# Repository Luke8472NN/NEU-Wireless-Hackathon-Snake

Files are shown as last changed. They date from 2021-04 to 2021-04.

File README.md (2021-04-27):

# NEU-Wireless-Hackathon-Snake
Northeastern University Wireless Club 11/11/16 Hackathon Snake Game.

Copied from my old profile, https://github.com/Luke8472

Eternally grateful for https://github.com/devendrashivraj for the board design!

## Description
A Snake Game coded in Arduino and uploaded to an Arduino Uno. A PCB was designed as a shield for the Arduino Uno, and to house all electronic components.

 

## How it Works
1) Turn the game on, using the power switch located in the upper left corner of the PCB.
2) Press the joystick once, to start playing the game.
3) The direction of the snake can be controlled using the joystick.
4) The speed of the snake can be controlled using the potentiometer located to the left of the joystick.
5) The option for walls on or off can be controlled by the switch below the potentiometer. </br>
   a) If the walls are on, the user loses if the snake hits the edge of the display. </br>
   b) If the walls are off, the snake can go out one edge, and come in through the other (world wraps around).
6) The score is displayed above the joystick, and represents the number of candies eaten by the snake.
7) If the game is left idle for more than 15 seconds, a Snake AI will begin playing the game.

## Goal of the Game
Eat all of the candy without having the snake cross over itself. Once the snake grows to the size of the display (score = 128), the user wins.

## Prerequisites
LedControl library: https://github.com/wayoda/LedControl

## Board Design


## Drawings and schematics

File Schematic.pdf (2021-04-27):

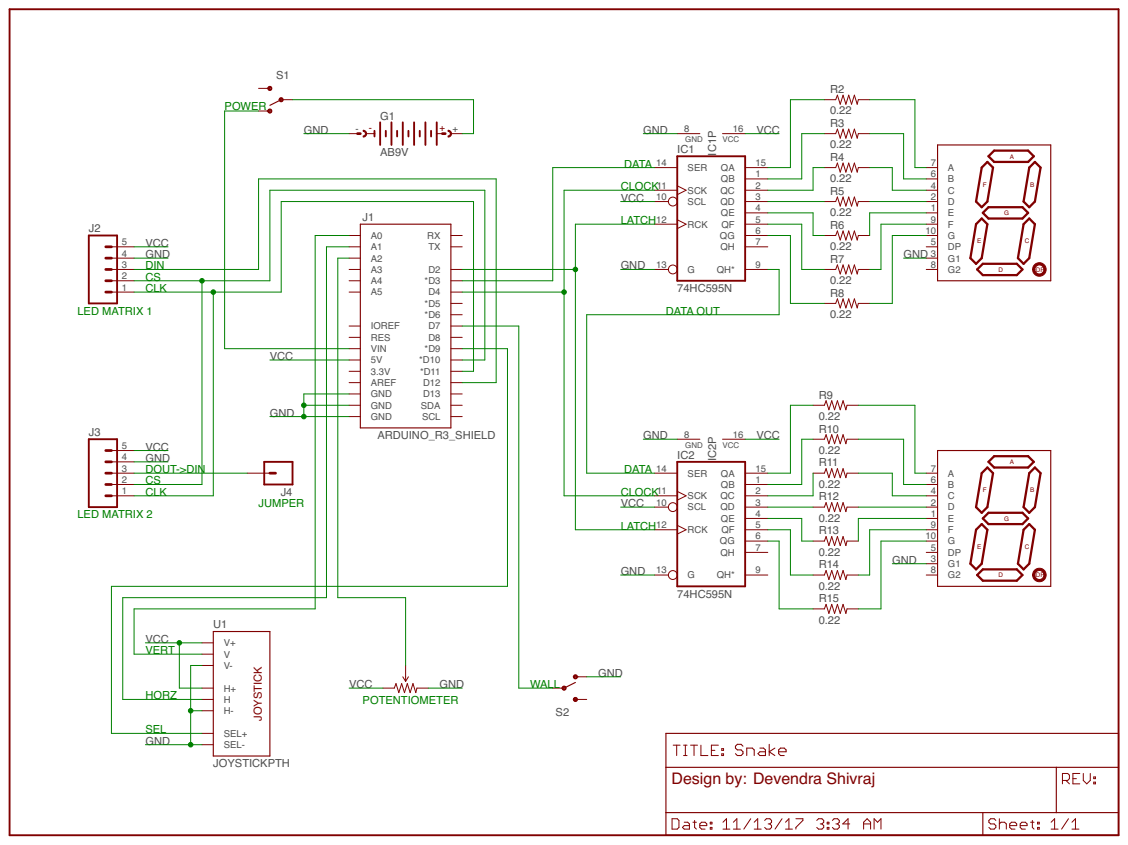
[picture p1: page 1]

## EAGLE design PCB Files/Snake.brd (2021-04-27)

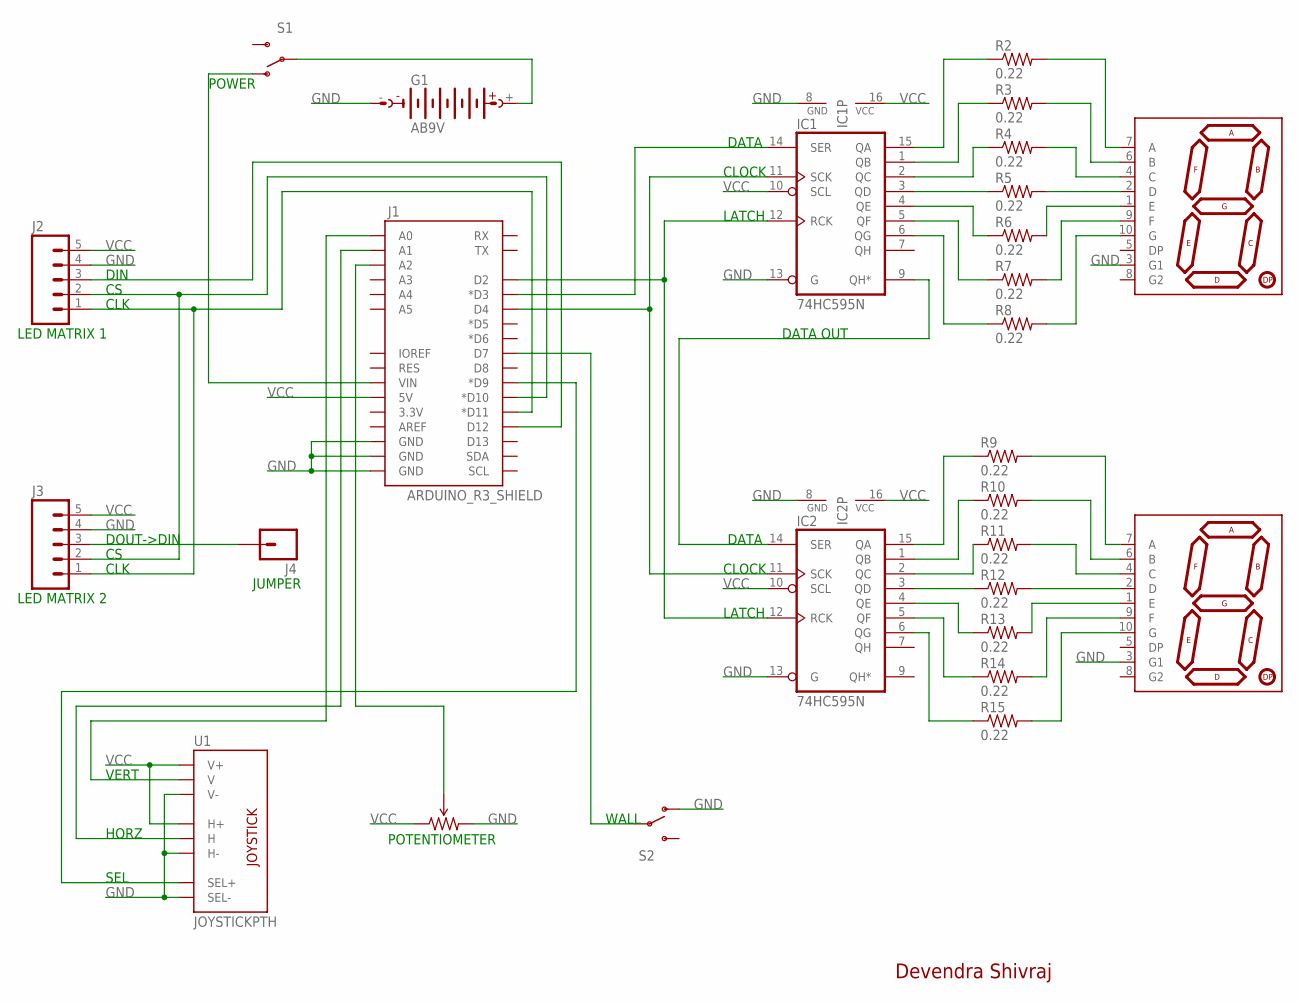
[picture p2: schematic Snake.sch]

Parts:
G1: AB9V
IC1, IC2: 74HC595N; DIL16
J1: ARDUINO_R3_SHIELD; UNO_R3_SHIELD
J2, J3: M05PTH; 1X05
J4: M01PTH; 1X01
R1: TSR-3386; 3386U
R2, R3, R4, R5, R6, R7, R8, R9, R10, R11, R12, R13, R14, R15: 0.22; 0805
S1, S2: SWITCH-SPDTPTH; SWITCH-SPDT
U1: JOYSTICKPTH; JOYSTICK
U$1, U$2: 7-SEGMENT-DISPLAYPTH; 7-SEGMENT-DISPLAY

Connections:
+: G1.+, S1.2
A2: J1.A2, R1.2 (WIPER)
CLK: J1.D11 (*D11), J2.1, J3.1
CLOCK: IC1.11 (SCK), IC2.11 (SCK), J1.D4
CS: J1.D10 (*D10), J2.2, J3.2
DATA: IC1.14 (SER), J1.D3 (*D3)
DATA_SHIFT: IC1.9 (QH*), IC2.14 (SER)
DIN: J1.D12, J2.3
GND: G1.-, IC1.8 (GND), IC1.13 (G), IC2.8 (GND), IC2.13 (G), J1.GND@0 (GND), J1.GND@1 (GND), J1.GND@2 (GND), J2.4, J3.4, R1.3 (CW), S2.1 (O), U1.B2A (SEL-), U1.H3 (H-), U1.V3 (V-), U$1.3 (G1), U$2.3 (G1)
HORZ: J1.A1, U1.H2 (H)
LATCH: IC1.12 (RCK), IC2.12 (RCK), J1.D2
unnamed: J3.3, J4.1
unnamed: J1.VIN, S1.1 (O)
unnamed: IC1.15 (QA), R2.1
unnamed: IC1.1 (QB), R3.1
unnamed: IC1.2 (QC), R4.1
unnamed: IC1.3 (QD), R5.1
unnamed: IC1.4 (QE), R6.1
unnamed: IC1.5 (QF), R7.1
unnamed: IC1.6 (QG), R8.1
unnamed: R2.2, U$1.7 (A)
unnamed: R3.2, U$1.6 (B)
unnamed: R4.2, U$1.4 (C)
unnamed: R5.2, U$1.2 (D)
unnamed: R6.2, U$1.1 (E)
unnamed: R7.2, U$1.9 (F)
unnamed: R8.2, U$1.10 (G)
unnamed: IC2.15 (QA), R9.1
unnamed: J1.D7, S2.2
unnamed: IC2.1 (QB), R10.1
unnamed: IC2.2 (QC), R11.1
unnamed: IC2.3 (QD), R12.1
unnamed: IC2.4 (QE), R13.1
unnamed: IC2.5 (QF), R14.1
unnamed: IC2.6 (QG), R15.1
unnamed: R9.2, U$2.7 (A)
unnamed: R10.2, U$2.6 (B)
unnamed: R11.2, U$2.4 (C)
unnamed: R12.2, U$2.2 (D)
unnamed: R13.2, U$2.1 (E)
unnamed: R14.2, U$2.9 (F)
unnamed: R15.2, U$2.10 (G)
SEL: J1.D9 (*D9), U1.B1A (SEL+)
VCC: IC1.10 (SCL), IC1.16 (VCC), IC2.10 (SCL), IC2.16 (VCC), J1.5V, J2.5, J3.5, R1.1 (CCW), U1.H1 (H+), U1.V1 (V+)
VERT: J1.A0, U1.V2 (V)

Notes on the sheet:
DATA
CLOCK
LATCH
DATA OUT
VERT
HORZ
SEL
WALL
DIN
CLK
POWER
LED MATRIX 1
LED MATRIX 2
POTENTIOMETER
JUMPER
DOUT->DIN
Devendra Shivraj

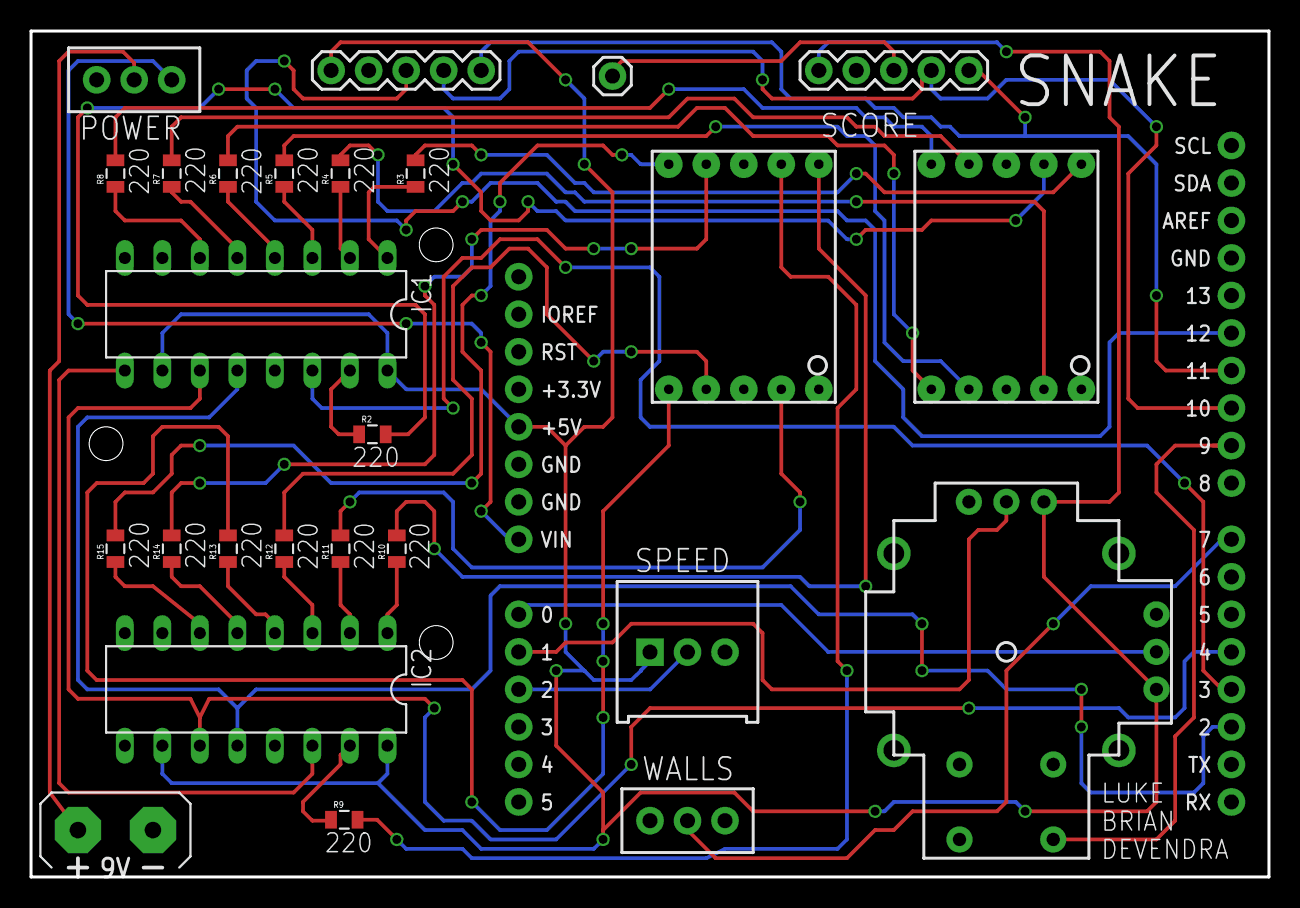
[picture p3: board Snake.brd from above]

Board: 2 copper layers, 83.8 x 57.3 mm, 27 parts (0 on the bottom side), 45 nets.

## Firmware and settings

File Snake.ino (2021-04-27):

#include "LedControl.h"
#include <avr/pgmspace.h>
const byte SPACE[5] PROGMEM = {B00000000, B00000000, B00000000, B00000000, B00000000}; // SPACE
const byte A[5] PROGMEM = {B01111110, B00010001, B00010001, B01111110, B00000000}; // A
const byte B[5] PROGMEM = {B01111111, B01001001, B01001001, B00110110, B00000000}; // B
const byte C[5] PROGMEM = {B00111110, B01000001, B01000001, B00100010, B00000000}; // C
const byte D[5] PROGMEM = {B01111111, B01000001, B01000001, B00111110, B00000000}; // D
const byte E[5] PROGMEM = {B01111111, B01001001, B01001001, B01000001, B00000000}; // E
const byte F[5] PROGMEM = {B01111111, B00001001, B00001001, B00000001, B00000000}; // F
const byte G[5] PROGMEM = {B00111110, B01000001, B01001001, B01111010, B00000000}; // G
const byte H[5] PROGMEM = {B01111111, B00001000, B00001000, B01111111, B00000000}; // H
const byte I[5] PROGMEM = {B01000001, B01111111, B01000001, B00000000, B00000000}; // I
const byte J[5] PROGMEM = {B00110000, B01000000, B01000001, B00111111, B00000000}; // J
const byte K[5] PROGMEM = {B01111111, B00001000, B00010100, B01100011, B00000000}; // K
const byte L[5] PROGMEM = {B01111111, B01000000, B01000000, B01000000, B00000000}; // L
const byte M[5] PROGMEM = {B01111111, B00000010, B00001100, B00000010, B01111111}; // M
const byte N[5] PROGMEM = {B01111111, B00000100, B00001000, B00010000, B01111111}; // N
const byte O[5] PROGMEM = {B00111110, B01000001, B01000001, B00111110, B00000000}; // O
const byte P[5] PROGMEM = {B01111111, B00001001, B00001001, B00000110, B00000000}; // P
const byte Q[5] PROGMEM = {B00111110, B01000001, B01000001, B10111110, B00000000}; // Q
const byte R[5] PROGMEM = {B01111111, B00001001, B00001001, B01110110, B00000000}; // R
const byte S[5] PROGMEM = {B01000110, B01001001, B01001001, B00110010, B00000000}; // S
const byte T[5] PROGMEM = {B00000001, B00000001, B01111111, B00000001, B00000001}; // T
const byte U[5] PROGMEM = {B00111111, B01000000, B01000000, B00111111, B00000000}; // U
const byte V[5] PROGMEM = {B00001111, B00110000, B01000000, B00110000, B00001111}; // V
const byte W[5] PROGMEM = {B00111111, B01000000, B00111000, B01000000, B00111111}; // W
const byte X[5] PROGMEM = {B01100011, B00010100, B00001000, B00010100, B01100011}; // X
const byte Y[5] PROGMEM = {B00000111, B00001000, B01110000, B00001000, B00000111}; // Y
const byte Z[5] PROGMEM = {B01100001, B01010001, B01001001, B01000111, B00000000}; // Z
const int SEGMENT[10] PROGMEM = {63, 6, 91, 79, 102, 109, 125, 7, 127, 103}; // 7 segment display

/*
 pin D12 is connected to the DataIn
 pin D11 is connected to the CLK
 pin D10 is connected to CS
 
 pin A0 is connected to Vertical
 pin A1 is connected to Horizontal
 pin D9 is connected to the button
 */
LedControl lc = LedControl(12,11,10,2);

int latchPin = 2;
int dataPin = 3;
int clockPin = 4;

int toggle, dir;
int array[16][8]; //column, row
int len = 1;
bool isCandy = true, hasLost = true;
int headX = 0, headY = 4;
int del = 50;
//bool isOpenWall = true; // now digitalRead(7) is used
bool isAI = false;
int candyX, candyY;
int brightness = 1;

void setup() {
  /*
   The MAX72XX is in power-saving mode on startup,
   we have to do a wakeup call
   */
  lc.shutdown(0,false);
  lc.shutdown(1,false);
  
  /* Set the brightness to a medium values */
  lc.setIntensity(0,brightness);
  lc.setIntensity(1,brightness);
  
  /* and clear the display */
  lc.clearDisplay(0);
  lc.clearDisplay(1);

  pinMode(9, INPUT);
  digitalWrite(9, HIGH); // to toggle button
  pinMode(7, INPUT);
  digitalWrite(7, HIGH); // to isOpenWall switch

  Serial.begin(9600);

  pinMode(latchPin, OUTPUT);
  pinMode(dataPin, OUTPUT);
  pinMode(clockPin, OUTPUT);
}

void displayBoard() {
  for(int i=0; i<16; i++) {
    for(int j=0; j<8; j++) {
      if(i<8) {
        lc.setLed(0,i,j,array[i][j]!=0);
      }
      else {
        lc.setLed(1,i-8,j,array[i][j]!=0);
      }
    }
  }
}
void negDisplayBoard() {
  for(int i=0; i<16; i++) {
    for(int j=0; j<8; j++) {
      if(i<8) {
        lc.setLed(0,i,j,array[i][j]==0);
      }
      else {
        lc.setLed(1,i-8,j,array[i][j]==0);
      }
    }
  }
}

void increment() {
  if(digitalRead(7) == LOW) { // swich is closed so walls are open //!isOpenWall) {
    if((dir==0 && headY==7) || (dir==1 && headX==15) || (dir==2 && headY==0) || (dir==3 && headX==0)) {
      hasLost = true;
    }
  }
  
  if(!hasLost) {
    for(int i=0; i<16; i++) {
      for(int j=0; j<8; j++) {
        if(array[i][j] > 0) {
          array[i][j]++;
        }
      }
    }
    
    if(dir==0) {
      headY = (headY+1)%8;
      isCandy = (array[headX][headY]==-1);
      hasLost = (array[headX][headY]>1);
      array[headX][headY] = 1;
    }
    else if(dir==1) {
      headX = (headX+1)%16;
      isCandy = (array[headX][headY]==-1);
      hasLost = (array[headX][headY]>1);
      array[headX][headY] = 1;
    }
    else if(dir==2) {
      headY = (headY+7)%8;
      isCandy = (array[headX][headY]==-1);
      hasLost = (array[headX][headY]>1);
      array[headX][headY] = 1;
    }
    else {
      headX = (headX+15)%16;
      isCandy = (array[headX][headY]==-1);
      hasLost = (array[headX][headY]>1);
      array[headX][headY] = 1;
    }
    
    if(isCandy) {
      len++;
    }
    else {
      for(int i=0; i<16; i++) {
        for(int j=0; j<8; j++) {
          if(array[i][j] == len+1) {
            array[i][j] = 0;
          }
        }
      }
    }
  }
}

void scrollText(String s, int wait) {
  //int i=-17; // -17 to make text scroll from right with 17 col offset
  //while(true) {
  for(int i=-17; i<wait/50 - 17; i++) { // wait i time scrolling before going to animation
    for(int j=0; j<8; j++) {
      if(j+i >= 0) {
        byte testByte = getTextByte(s,(j+i)%(6*s.length()));
        lc.setRow(0,j,testByte);
      }
    }
    for(int j=0; j<8; j++) { // for some reason it didn't do j=0 to 15 & board j/8
      if(j+i+8 >= 0) {
        byte testByte = getTextByte(s,(j+i+8)%(6*s.length()));
        lc.setRow(1,j,testByte);
      }
    }
    delay(50);
    //i++;
    
    if(digitalRead(9) == LOW) {hasLost = false; isAI = false; return;}
  }
  hasLost = false; // new since method's outer for loop
  isAI = true;
}

byte getTextByte(String s, int byteNum) {
  byte z = B00000000;
  if(s[byteNum/6] == ' ') {if(byteNum%6 == 5) {return z;} else {return pgm_read_byte_near(SPACE + byteNum%6);} }
  else if(s[byteNum/6] == 'A') {if(byteNum%6 == 5) {return z;} else {return pgm_read_byte_near(A + byteNum%6);} }
  else if(s[byteNum/6] == 'B') {if(byteNum%6 == 5) {return z;} else {return pgm_read_byte_near(B + byteNum%6);} }
  else if(s[byteNum/6] == 'C') {if(byteNum%6 == 5) {return z;} else {return pgm_read_byte_near(C + byteNum%6);} }
  else if(s[byteNum/6] == 'D') {if(byteNum%6 == 5) {return z;} else {return pgm_read_byte_near(D + byteNum%6);} }
  else if(s[byteNum/6] == 'E') {if(byteNum%6 == 5) {return z;} else {return pgm_read_byte_near(E + byteNum%6);} }
  else if(s[byteNum/6] == 'F') {if(byteNum%6 == 5) {return z;} else {return pgm_read_byte_near(F + byteNum%6);} }
  else if(s[byteNum/6] == 'G') {if(byteNum%6 == 5) {return z;} else {return pgm_read_byte_near(G + byteNum%6);} }
  else if(s[byteNum/6] == 'H') {if(byteNum%6 == 5) {return z;} else {return pgm_read_byte_near(H + byteNum%6);} }
  else if(s[byteNum/6] == 'I') {if(byteNum%6 == 5) {return z;} else {return pgm_read_byte_near(I + byteNum%6);} }
  else if(s[byteNum/6] == 'J') {if(byteNum%6 == 5) {return z;} else {return pgm_read_byte_near(J + byteNum%6);} }
  else if(s[byteNum/6] == 'K') {if(byteNum%6 == 5) {return z;} else {return pgm_read_byte_near(K + byteNum%6);} }
  else if(s[byteNum/6] == 'L') {if(byteNum%6 == 5) {return z;} else {return pgm_read_byte_near(L + byteNum%6);} }
  else if(s[byteNum/6] == 'M') {if(byteNum%6 == 5) {return z;} else {return pgm_read_byte_near(M + byteNum%6);} }
  else if(s[byteNum/6] == 'N') {if(byteNum%6 == 5) {return z;} else {return pgm_read_byte_near(N + byteNum%6);} }
  else if(s[byteNum/6] == 'O') {if(byteNum%6 == 5) {return z;} else {return pgm_read_byte_near(O + byteNum%6);} }
  else if(s[byteNum/6] == 'P') {if(byteNum%6 == 5) {return z;} else {return pgm_read_byte_near(P + byteNum%6);} }
  else if(s[byteNum/6] == 'Q') {if(byteNum%6 == 5) {return z;} else {return pgm_read_byte_near(Q + byteNum%6);} }
  else if(s[byteNum/6] == 'R') {if(byteNum%6 == 5) {return z;} else {return pgm_read_byte_near(R + byteNum%6);} }
  else if(s[byteNum/6] == 'S') {if(byteNum%6 == 5) {return z;} else {return pgm_read_byte_near(S + byteNum%6);} }
  else if(s[byteNum/6] == 'T') {if(byteNum%6 == 5) {return z;} else {return pgm_read_byte_near(T + byteNum%6);} }
  else if(s[byteNum/6] == 'U') {if(byteNum%6 == 5) {return z;} else {return pgm_read_byte_near(U + byteNum%6);} }
  else if(s[byteNum/6] == 'V') {if(byteNum%6 == 5) {return z;} else {return pgm_read_byte_near(V + byteNum%6);} }
  else if(s[byteNum/6] == 'W') {if(byteNum%6 == 5) {return z;} else {return pgm_read_byte_near(W + byteNum%6);} }
  else if(s[byteNum/6] == 'X') {if(byteNum%6 == 5) {return z;} else {return pgm_read_byte_near(X + byteNum%6);} }
  else if(s[byteNum/6] == 'Y') {if(byteNum%6 == 5) {return z;} else {return pgm_read_byte_near(Y + byteNum%6);} }
  else if(s[byteNum/6] == 'Z') {if(byteNum%6 == 5) {return z;} else {return pgm_read_byte_near(Z + byteNum%6);} }
}

void displayScore(int score) {
  digitalWrite(latchPin, LOW);
  shiftOut(dataPin, clockPin, MSBFIRST, pgm_read_byte_near(SEGMENT + score%10));
  shiftOut(dataPin, clockPin, MSBFIRST, pgm_read_byte_near(SEGMENT + score/10));
  digitalWrite(latchPin, HIGH);
}

void setUpBoard() {
  len = 1;
  headX = 0;
  headY = 4;
  for(int i=0; i<16; i++) {
    for(int j=0; j<8; j++) {
      array[i][j] = 0;
    }
  }
  dir=1;
  array[headX][headY]=1;
  randomSeed(analogRead(5));
  candyX = random(16);
  candyY = random(8);
  if(candyX!=0 or candyY!=4) {array[candyX][candyY] = -1;}
  isCandy = false;
}

int bestAIDir() { //add no walls and maze-solving algorithms
  int first, second, third, fourth;
  if(candyX-headX>=0 && candyY-headY>=0 && candyY-headY>=candyX-headX) {first=0; second=1; third=2; fourth=3;}
  else if(candyX-headX>=0 && candyY-headY>=0 && candyY-headY<candyX-headX) {first=1; second=0; third=2; fourth=3;}
  else if(candyX-headX>=0 && candyY-headY<0 && headY-candyY>=candyX-headX) {first=2; second=1; third=0; fourth=3;}
  else if(candyX-headX>=0 && candyY-headY<0 && headY-candyY<candyX-headX) {first=1; second=2; third=0; fourth=3;}
  else if(candyX-headX<0 && candyY-headY>=0 && candyY-headY>=headX-candyX) {first=0; second=3; third=1; fourth=2;}
  else if(candyX-headX<0 && candyY-headY>=0 && candyY-headY<headX-candyX) {first=3; second=0; third=1; fourth=2;}
  else if(candyX-headX<0 && candyY-headY<0 && headY-candyY>=headX-candyX) {first=2; second=3; third=0; fourth=1;}
  else if(candyX-headX<0 && candyY-headY<0 && headY-candyY<headX-candyX) {first=3; second=2; third=0; fourth=1;}
  
  else {first=0; second=1;} // when does this happen???
  
  Serial.println(first);
  Serial.println(second);
  Serial.println(" ");
  if(canMove(first)) {return first;}
  if(canMove(second)) {return second;}
  if(canMove(third)) {return third;}
  else {return fourth;}
}
bool canMove(int dirAI) {
  if((dirAI==0 && headY<7 && array[headX][headY+1]<1) ||
     (dirAI==1 && headX<15 && array[headX+1][headY]<1) ||
     (dirAI==2 && headY>0 && array[headX][headY-1]<1) ||
     (dirAI==3 && headX>0 && array[headX-1][headY]<1)) {return true;}
   else {return false;}
}

void loop() {
  displayScore(0);
  
  if(hasLost) {scrollText("SNAKE ", 12000);}
  
  setUpBoard();
  displayBoard();

  delay(1000);
  
  while(!hasLost) {
    displayScore(len-1);
    
    if(!isAI && digitalRead(9) == LOW) {
      delay(250);
      while(digitalRead(9) == HIGH) {}
      delay(250);
    }
    
    if(isCandy) {
      randomSeed(analogRead(5));
      candyX = random(16);
      candyY = random(8);
      while(array[candyX][candyY] != 0) {
        candyX = random(16);
        candyY = random(8);
      }
      array[candyX][candyY] = -1;
      isCandy = false;
    }
    
    del = analogRead(A2)/3; // speed determination from pot input
    if(!isAI) {
      for(int i=0; i<=del/10; i++) {
        delay(10);
        if(analogRead(A0)>824)
          {toggle=0;}
        else if(analogRead(A0)<200)
          {toggle=2;}
        else if(analogRead(A1)>824)
          {toggle=3;}
        else if(analogRead(A1)<200)
          {toggle=1;}
        else
          {toggle=-1;}
      }
      
      if((dir==0 || dir==2) && (toggle==1 || toggle==3))
        {dir=toggle;}
      else if((dir==1 || dir==3) && (toggle==0 || toggle==2))
        {dir=toggle;}
    }
    else {
      dir = bestAIDir();
      if(digitalRead(9) == LOW) {isAI = false; delay(1000-del); setUpBoard();}
      delay(del);
    }
    
    displayBoard();
    increment();
  }
  
  delay(1000);
  for(int count=0; count<6; count++) {
    delay(100);
    displayBoard();
    delay(100);
    //negDisplayBoard();
    lc.clearDisplay(0);
    lc.clearDisplay(1);
  }

  if(!isAI) {
    if(len >= 99) {scrollText("WINNER ", 12000);} //maximum of 128
    else {scrollText("LOSER ", 12000);}
  }
}

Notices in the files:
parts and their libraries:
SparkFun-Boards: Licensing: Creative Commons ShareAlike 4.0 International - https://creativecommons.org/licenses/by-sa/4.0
